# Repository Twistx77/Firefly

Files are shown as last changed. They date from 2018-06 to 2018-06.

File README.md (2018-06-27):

# Firefly <h1> 
Open WIFI-enabled RGB lamp with temperature, humidity, suspended air particles and eCO2 sensors.

# List of components <h2> 

| Quantity | Component | Image |
| --- | --- | --- |
| 1 | ESP8266 Wemos D1 Mini |  |
| 10 | WS2812B |  |
|12 		| Capacitor 0603 0.1uF |Resultado de imagen de smd resistor 0603|
|2			| Resistor 0603 |Resultado de imagen de capacitor 0603|
|1			| APDS-9960	Breakout Board|![Resultado de imagen de apds 9960 board]()|
|(Optional)* 1 	| DHT11 |Resultado de imagen de dht11|
|(Optional)* 1 | CCS811 + HDC1080 Breakout Board |CJMCU8118-CCS811-HDC1080-CARBON-MONOXIDE-CO-VOCS-TEMPERATURE-AND-HUMIDITY-GAS|

*Even though both components can be soldered to the same board or none of them, it is recommended to chose the CCS811 + HDC1080 module if you can pay it since it not only provides more information (TVOC 's and eCO2) but the temperature and humidity measurements are more accurate.

You can get all this components in different websites and I have found that Aliexpress is the cheapest one for most of these modules.

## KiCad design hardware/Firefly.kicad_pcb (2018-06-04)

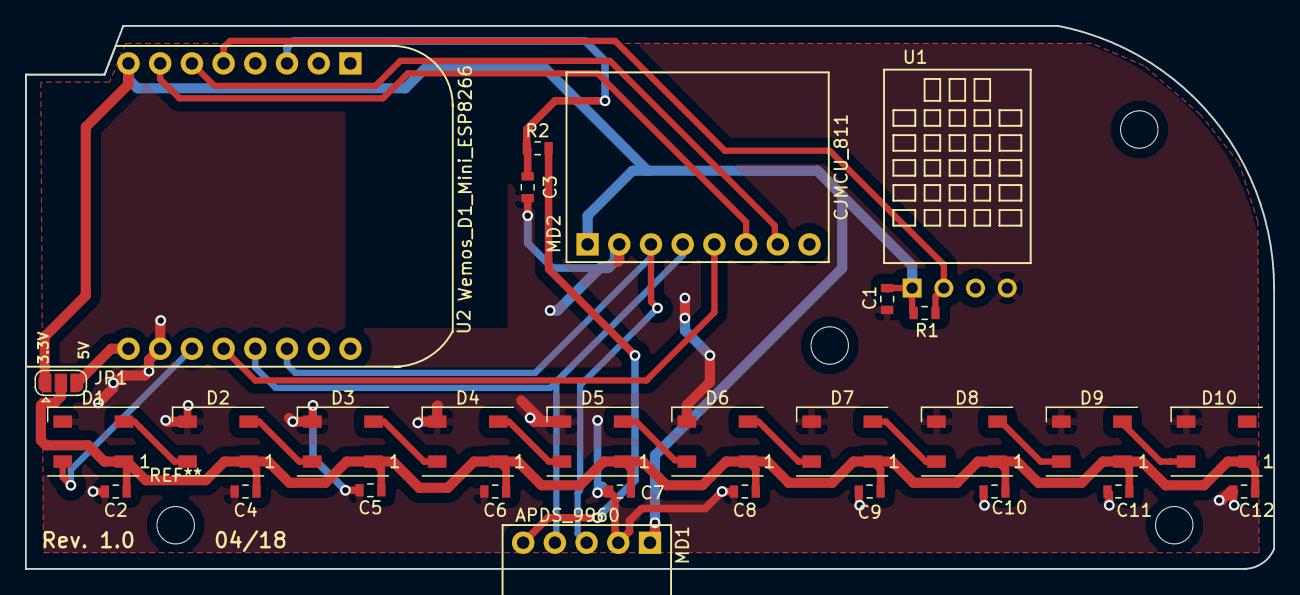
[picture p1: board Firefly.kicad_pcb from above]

Board: 2 copper layers, 100.0 x 43.5 mm, 29 parts (0 on the bottom side), 22 nets.

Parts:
C1, C2, C3, C4, C5, C6, C7, C8, C9, C10, C11, C12: 0.1uF; C_0603_1608Metric
D1, D2, D3, D4, D5, D6, D7, D8, D9, D10: WS2812B; LED_WS2812B_PLCC4_5.0x5.0mm_P3.2mm
JP1: SolderJumper_3_Open; SolderJumper-3_P1.3mm_Open_RoundedPad1.0x1.5mm
MD1: APDS-9960; MODULE_APDS_9960
MD2: CJMCU-811; MODULE_CJMCU_811
R1, R2: 1K; R_0603_1608Metric
U1: DHT11
U2: ESP8266_D1; Wemos_D1_Mini_ESP8266

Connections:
+3V3: C1.1, JP1.1, MD1.1, MD2.1, R1.1, U1.1, U2.8
+5V: JP1.3, U2.9
/D4: D1.4, U2.11
/D6: R1.2, U1.2, U2.5
/SCL: MD1.3, MD2.3, U2.14
/SDA: MD1.4, MD2.4, U2.13
GND: C1.2, C2.2, C3.2, C4.2, C5.2, C6.2, C7.2, C8.2, C9.2, C10.2, C11.2, C12.2, D1.3, D2.3, D3.3, D4.3, D5.3, D6.3, D7.3, D8.3, D9.3, D10.3, MD1.2, MD2.2, U1.4, U2.10
unnamed: C3.1, R2.2, U2.3
unnamed: C2.1, C4.1, C5.1, C6.1, C7.1, C8.1, C9.1, C10.1, C11.1, C12.1, D1.1, D2.1, D3.1, D4.1, D5.1, D6.1, D7.1, D8.1, D9.1, D10.1, JP1.2
unnamed: D1.2, D2.4
unnamed: D2.2, D3.4
unnamed: D3.2, D4.4
unnamed: D4.2, D5.4
unnamed: D5.2, D6.4
unnamed: D6.2, D7.4
unnamed: D7.2, D8.4
unnamed: D8.2, D9.4
unnamed: D9.2, D10.4
unnamed: MD1.5, R2.1
unnamed: MD2.5, U2.12
unnamed: MD2.6, U2.7
unnamed: MD2.7, U2.6

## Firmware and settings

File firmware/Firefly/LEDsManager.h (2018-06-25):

#ifndef _LEDS_MANAGER_H
#define _LEDS_MANAGER_H


#include "Arduino.h"
#include <Adafruit_NeoPixel.h>

#define DEFAULT_LED_PIN 2
#define DEFAULT_NUM_LEDS 10

#define MAX_PREDEFINED_COLORS 7
#define MAX_PREDEFINED_BRIGHTNESS_INDEX 10


#define DELAY_EFFECTS 100

#define EFFECT_NONE 0 
#define EFFECT_RAINBOW 1
#define EFFECT_BREATHING 2
#define EFFECT_CHASER 3

class LEDsManager 
{
  public:
   LEDsManager( uint8_t aNum_LEDs = DEFAULT_NUM_LEDS, uint8_t aLEDs_PIN = DEFAULT_LED_PIN );
   void init ( uint8_t aInitialBrightness = 25 );
   void setColor( uint8_t aR, uint8_t aG, uint8_t aB );
   void setColor( uint32_t aColor );
   void setBrightness( uint8_t aBrightness); 
   void switchLamp( void );
   void nextColor( void );
   void nextBrightness( void );
   void setEffect ( uint8_t aEffect );
   void runEffect( void );
   
 private:
  uint8_t LEDs_PIN;  
  uint32_t currentColor;
  uint8_t currentBrightness;
  uint8_t lampON;
  uint8_t currentEffect;
  uint8_t currentColorIndex;
  uint8_t currentBrightnessIndex; 
  
  void effectRainbow(); 
  void effectBreathing();
  void effectChaser(); 
  uint32_t Wheel(byte WheelPos);
 
    

};

#endif

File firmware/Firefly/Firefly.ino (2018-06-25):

#include <TaskScheduler.h>
#include <ESP8266WiFi.h>
#include <WiFiClient.h>

#include "GestureHandler.h"
#include "SensorsManager.h"
#include "LEDsManager.h"

#define SAMPLING_PERIOD 5000


const char* ssid     = "RED_TUTOELECTRO";
const char* password = "tutoelectro123";

//const char* ssid     = "FISIO_WF";
//const char* password = "fisfosFUS";
const uint16_t port = 8266;

WiFiServer TCPServer(port);
WiFiClient TCPClient; 


bool clientConnected = false;

SensorsManager sensorManager = (true, false, true);
GestureHandler gestureHandler;
LEDsManager ledsManager;



void decodeSET (String aPacket);
void decodeCommand(String aPacket);

void checkConnectionStatus();
void sampleSensors();
void checkForGestures();
void runEffects();

uint32_t currentColor = 0;

Task task_ConnectionStatus(100, TASK_FOREVER, &checkConnectionStatus);
Task task_GestureHandler(20, TASK_FOREVER, &checkForGestures);
Task task_LedsManager(100, TASK_FOREVER, &runEffects);
Task task_SensorManager(SAMPLING_PERIOD, TASK_FOREVER, &sampleSensors);

Scheduler scheduler; 
   
void setup() 
{  

  Serial.begin(115200);
  
  ledsManager.init(30);   
  sensorManager.init();
  gestureHandler.init();
  

  WiFi.mode(WIFI_STA);
  WiFi.begin(ssid, password);

  while (WiFi.status() != WL_CONNECTED) {
    delay(500);
    Serial.print(".");
  }

  Serial.println("");
  Serial.println("WiFi connected");  
  Serial.println("IP address: ");
  Serial.println(WiFi.localIP());

  TCPServer.begin();

  scheduler.addTask(task_ConnectionStatus);
  scheduler.addTask(task_GestureHandler);
  scheduler.addTask(task_SensorManager);
  scheduler.addTask(task_LedsManager);

  task_ConnectionStatus.enable();
  task_GestureHandler.enable();
  task_SensorManager.enable();
  task_LedsManager.enable(); 
}

void loop() 
{

  scheduler.execute();
  

}

void checkConnectionStatus()
{

  if (!TCPClient.connected()) {
        // try to connect to a new client
        TCPClient = TCPServer.available();
        clientConnected = false;
  }    

  else 
  {
        clientConnected = true;  
        if (TCPClient.available() > 0)    //Check for new data
        { 
            String packet = TCPClient.readStringUntil('\r'); 

            Serial.print ("Received: ");
            Serial.println(packet);
                        
            decodeCommand(packet);
        }
  }
  
}

void decodeCommand(String aPacket)
{  
  String command = aPacket.substring(0,3);

  if (command.equals("GET"))
  {
    //To be implemented
  }
  else if ( command.equals ("SET"))
  {
    decodeSET(aPacket);  
  } 
}

void decodeSET (String aPacket)
{  
  String command = aPacket.substring(4,7);  
  
  if (command.equals("COL"))  // S E T   C O L   2 5  5     2  5  5     2  5  5     1  0  0 \r
                              // 0 1 2 3 4 5 6 7 8 9 10 11 12 13 14 15 16 17 18 19 20 21 22 23
  {
    uint8_t r = aPacket.substring(8,11).toInt(); 
    uint8_t g = aPacket.substring(12,15).toInt(); 
    uint8_t b = aPacket.substring(16,19).toInt(); 
    uint8_t i = aPacket.substring(20,23).toInt();   
    currentColor = (( uint32_t ) r << 16 ) | (( uint32_t )g << 8) | b;
    ledsManager.setColor(currentColor);
    ledsManager.setBrightness(i);
  } 
  else if (command.equals("EFE"))
  {    
    String effect = aPacket.substring(8,11);

    if (effect.equals("RAI"))
    {      
      ledsManager.setEffect(EFFECT_RAINBOW);
    }
    else if( effect.equals("BRE"))
    {
      ledsManager.setEffect(EFFECT_BREATHING);
    }
    else if (effect.equals("CHA"))
    {
      ledsManager.setEffect(EFFECT_CHASER);
    }
    else if (effect.equals("NON"))
    {
      ledsManager.setEffect(EFFECT_NONE);      
    }    
  }  
}

void sampleSensors()
{
  sensorManager.sampleSensors();

  if (TCPClient.connected())
  {
     String sensorsDataString = "SEN TEMP:" + String(sensorManager.getTemperature());
     sensorsDataString += " HUM:" + String (sensorManager.getHumidity());
     sensorsDataString += " eCO2:" + String (sensorManager.getECO2());
     sensorsDataString += " TVOC:" + String (sensorManager.getTVOC());
     Serial.print("Sent: ");
     Serial.println(sensorsDataString);
     TCPClient.write( sensorsDataString.c_str() );
  }
}

void checkForGestures()
{  
  gestureHandler.checkForGestures();
}

void runEffects()
{
  ledsManager.runEffect();
}

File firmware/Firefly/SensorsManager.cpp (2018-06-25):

#include "SensorsManager.h"


SensorsManager::SensorsManager( bool aDHT_EN, bool aHDC1080_EN, bool aCCS811_EN ) 
{       
  
  DHT_Pin = DHT_PIN;     
  DHT_EN = aDHT_EN;  
  HDC1080_EN = aHDC1080_EN;
  CCS811_EN = aCCS811_EN;  

  lastHumidity = 0;
  lastTemperature = 0;
}

void SensorsManager::init( void )
{
    if ( DHT_EN )
    {
        dht.setup(DHT_Pin); //Init DHT library 
    }
    
    if ( HDC1080_EN )
    {
    }

    pinMode(CCS811_WAKE_PIN, OUTPUT);
    pinMode(CCS811_RESET_PIN, OUTPUT);
    digitalWrite(CCS811_WAKE_PIN, HIGH); // Set wake pin high to keep the CCS811 asleep because it is interfering with apds9960
    digitalWrite(CCS811_WAKE_PIN, LOW);
    
    
    if ( CCS811_EN )
    {    
        

        if(!ccs.begin())
        {
            Serial.println("Sensor CCS811 not working or not wired correctly");   
        }
    }
}

void SensorsManager::sampleSensors( void )
{
 
   
  if ( DHT_EN )
  { 
    lastHumidity = dht.getHumidity();
    lastTemperature = dht.getTemperature();
    /*
    Serial.print("Humedad: ");
    Serial.print(lastHumidity, 1);
    Serial.print("\tTemperatura: ");
    Serial.print(lastTemperature, 1);
    */
  }
  
  if ( HDC1080_EN )
  { 
    lastHumidity = dht.getHumidity();
    lastTemperature = dht.getTemperature();
    /*
    Serial.print("Humedad: ");
    Serial.print(lastHumidity, 1);
    Serial.print("\tTemperatura: ");
    Serial.print(lastTemperature, 1);*/
  }
  
  if ( CCS811_EN )
  {  
      if(!ccs.readData())
      { 
            lastECO2 = ccs.geteCO2();
            lastTVOC = ccs.getTVOC();
            /*
            Serial.print("\tCO2: ");
            Serial.print(lastECO2);
            Serial.print("ppm,\t TVOC: ");
            Serial.print(lastTVOC);
            Serial.println("ppb");*/
      }
  }   
}

float SensorsManager::getTemperature ()
{
  return (lastTemperature);
}

float SensorsManager::getHumidity()
{
  return (lastHumidity);
}

float SensorsManager::getECO2()
{  
 return (lastECO2);  
}

float SensorsManager::getTVOC()
{  
 return (lastTVOC);  
}

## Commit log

2018-06-25 Implemented basic gesture functionality and added gerbers to hardware
    [Firefly-B.Cu.gbl, Firefly-B.Mask.gbs, Firefly-B.Paste.gbp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]
2018-06-25 Fixed space in Gerbers folder name
    [Firefly-B.Cu.gbl, Firefly-B.Mask.gbs, Firefly-B.Paste.gbp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]
